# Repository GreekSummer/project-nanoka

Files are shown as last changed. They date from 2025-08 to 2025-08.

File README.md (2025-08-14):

# project-nanoka
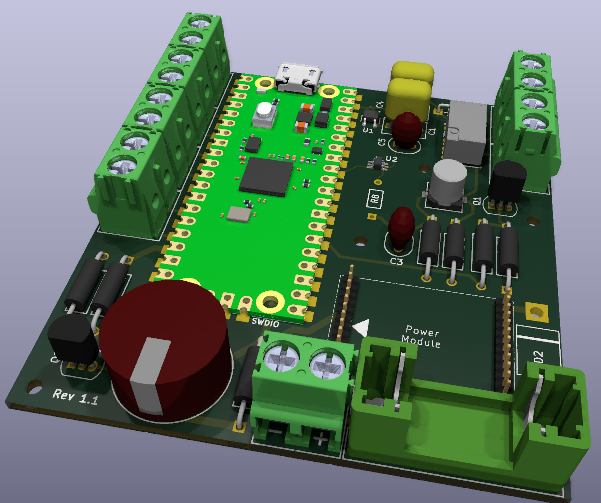
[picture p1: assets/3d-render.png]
KiCad 3D render


Project Nanoka is a Raspberry Pi Pico based audio output/input PCB. It exposes two audio terminals (input and output) as well as seven general-purposes input/output lines for external control. 

The PCB can be powered either through the Raspberry Pi's USB port, or through the power terminal. This requires a power module (also hosted on GitHub).

Right now, this is a prototype, and it's usefulness likely applies only to me. There are better solutions out there. I mainly created this to learn KiCad, and more broadly, PCB design which was always an interest of mine. This PCB should not be reproduced for your own personal use. If you do use it, **all responsibility is yours**. 

Known issues from previous version:
1. No audio output because the buffer chip is wired incorrectly (Input to A1, output to Y2)
2. Audio relay footprint is wrong
3. Audio relay footprint was accidentally flipped to the back of the board
4. C3 and C5 footprints are wrong
5. Audio input/output terminals are labelled in reverse
6. A potentiometer to adjust audio levels exists, but adjusting it below 220 ohms can cause damage to the Raspberry Pi

Fixed issues:
1. Audio is now properly routed from the buffer's A2 to Y2
2. Both relay issues have been fixed
3. Audio input/output terminals are labelled correctly and more clearly
4. C3 and C5 footprints fixed
5. Replaced potentiometer with a 220 ohm resistor

Improvements:
1. Replaced transistors with cheaper, more readily available ones
2. Tweaked transistor base resistor to draw less power from GPIO
4. Switched from a 4-layer setup to a 2-layer setup, making this cheaper to produce
5. Moved terminals closer to each other
6. General layout improvements
7. Symbols, footprints and 3D models are now packed in the repository

Ideas for the future:
1. Use a muxer IC to mix audio.
2. Switch from PWM audio to I2C audio for a cleaner signal.
3. Maybe re-design with SMD components to make this signafinantly smaller and elegant (but the THT components make it easier to assemble).

I have not yet re-produced this, so functionality and issues are unknown for this version.

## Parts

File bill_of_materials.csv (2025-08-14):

Country of Origin may be different at time of shipment.
The HTSUS and ECCN information shown is for informational purposes only and is not a representation or warranty as to the accuracy or reliability of these classifications. All information is provided "as is" and is subject to change without notice. Any use made of the information provided is without recourse to Digi-Key and at the user's risk.
Index | Manufacturer Part Number | Manufacturer Name | Description | Lead Time | Availability | Stock Status | Attrition % | Requested Quantity 1 | Pack Quantity 1 | Pack Type 1 | Digi-Key Part Number 1 | Unit Price 1 | Extended Price 1 | Minimum Order Quantity 1 | Customer Reference | Requested Part Number | Lead Weeks | Datasheet | Reference Designator | US Import Tariff | Note | Part Status | RoHS Status | Moisture Sensitivity Level (MSL) | ECCN | HTSUS | Country of Origin | Environmental Information | Original Part numbers | Image | Product Notes
1 | C330C105K5R5TA7301 | KEMET | CAP CER 1UF 50V X7R RADIAL | 2 past due; estimated in-stock on 01-Aug-2025 | 0 | Normally Stocking |  | 2 | 2 | Cut Tape (CT) | 399-9886-1-ND | 1.07000 | $2.14 | 1 | C1,C4 | 399-9886-1-ND | 12 | https://content.kemet.com/datasheets/KEM_C1050_GOLDMAX_X7R.pdf |  | - |  | Active | ROHS3 Compliant | Not Applicable | EAR99 | 8532.24.0060 | Mexico |  | 399-9886-1-ND | https://mm.digikey.com/Volume0/opasdata/d220001/medias/images/631/GoldenMax73-SERIES.jpg
2 | UUQ0J470MCL1GB | Nichicon | CAP ALUM 47UF 20% 6.3V SMD |  | 4,716 | In Stock |  | 1 | 1 | Cut Tape (CT) | 493-17489-1-ND | 0.53000 | $0.53 | 1 | C2 | 493-17489-1-ND | 25 | https://www.nichicon.co.jp/english/series_items/catalog_pdf/e-uuq.pdf |  | - |  | Active | ROHS3 Compliant | 1 (Unlimited) | EAR99 | 8532.22.0020 | Japan |  | 493-17489-1-ND | https://mm.digikey.com/Volume0/opasdata/d220001/medias/images/561/UUQ1E100MCL1GB.JPG
3 | 1N4148 | onsemi | DIODE STANDARD 100V 200MA DO35 |  | 179,368 | In Stock |  | 1 | 1 | Bulk | 1N4148FS-ND | 0.10000 | $0.10 | 1 | D1 | 1N4148FS-ND | 22 | https://www.onsemi.com/download/data-sheet/pdf/1n914-d.pdf |  | - |  | Active | ROHS3 Compliant | Not Applicable | EAR99 | 8541.10.0070 | China | https://www.onsemi.com/site/pdf/RoHS-statement.pdf|https://www.onsemi.com/PowerSolutions/MaterialComposition.do?export=pdf&opnId=1N4148 | 1N4148FS-ND | https://mm.digikey.com/Volume0/opasdata/d220001/medias/images/649/1N5229BFS.jpg
4 | 1N5408 | Diotec Semiconductor | DIODE STANDARD 1000V 3A DO201 |  | 12,757 | In Stock |  | 1 | 1 | Cut Tape (CT) | 4878-1N5408CT-ND | 0.33000 | $0.33 | 1 | D2 | 4878-1N5408CT-ND | 7 | https://diotec.com/request/datasheet/1n5400.pdf |  | - |  | Active | Not applicable | Not Applicable | EAR99 | 8541.10.0080 | China | https://diotec.com/request/imds/p3_e.pdf | 4878-1N5408CT-ND | https://mm.digikey.com/Volume0/opasdata/d220001/derivates/6/003/224/444/4878%7EDO201%7E%7E2_web%28640x640%29.jpg
5 | 696108003002 | Würth Elektronik | FUSEHOLDER BLOCKS - PCB - CLIP C | 1 past due; estimated in-stock on 04-Aug-2025 | 0 | Normally Stocking |  | 1 | 1 | Box | 732-11376-ND | 0.61000 | $0.61 | 1 | F1 | 732-11376-ND | 19 | https://www.we-online.com/katalog/datasheet/696108003002.pdf |  | - |  | Active | ROHS3 Compliant | Not Applicable | EAR99 | 8536.69.8000 | Romania | https://mm.digikey.com/Volume0/opasdata/d220001/medias/docus/744/Certificate_of_Compliance_ROHS.pdf | 732-11376-ND | https://mm.digikey.com/Volume0/opasdata/d220001/medias/images/2103/696108003002.JPG
6 | 696122003001 | Würth Elektronik | ACCESSORIES - PCB - CLIP COVER - |  | 16,278 | In Stock |  | 1 | 1 | Box | 732-11379-ND | 0.23000 | $0.23 | 1 | F1 | 732-11379-ND | 15 | https://www.we-online.com/katalog/datasheet/696122003001.pdf |  | - |  | Active | ROHS3 Compliant | Not Applicable | EAR99 | 8538.90.6000 | Romania | https://mm.digikey.com/Volume0/opasdata/d220001/medias/docus/744/Certificate_of_Compliance_ROHS.pdf | 732-11379-ND | https://mm.digikey.com/Volume0/opasdata/d220001/medias/images/2175/696122003001.JPG
7 | 1935161 | Phoenix Contact | TERM BLK 2POS SIDE ENTRY 5MM PCB |  | 83,502 | In Stock |  | 7 | 7 | Bulk | 277-1667-ND | 0.78000 | $5.46 | 1 | ST_20A | 277-1667-ND | 9 | https://mm.digikey.com/Volume0/opasdata/d220001/medias/docus/909/1935161.pdf |  | - |  | Active | ROHS3 Compliant | 1 (Unlimited) | EAR99 | 8536.90.4000 | China | https://www.phoenixcontact.com/en-us/products/product-compliance | 277-1667-ND | https://mm.digikey.com/Volume0/opasdata/d220001/medias/images/819/1935161.jpg
8 | IM03TS | TE Connectivity Potter & Brumfield Relays | RELAY TELECOM DPDT 2A 5V |  | 11,388 | In Stock |  | 1 | 1 | Tube | PB1094-ND | 4.55000 | $4.55 | 1 | K1 | PB1094-ND | 27 | https://www.te.com/commerce/DocumentDelivery/DDEController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 |  | - |  | Active | ROHS3 Compliant | 1 (Unlimited) | EAR99 | 8536.41.0020 | Portugal |  | PB1094-ND | https://mm.digikey.com/Volume0/opasdata/d220001/medias/images/666/IM-PC-SERIES.jpg
9 | CF14JT100R | Stackpole Electronics Inc | RES 100 OHM 5% 1/4W AXIAL |  | 197,065 | In Stock |  | 1 | 1 | Cut Tape (CT) | CF14JT100RCT-ND | 0.10000 | $0.10 | 1 | R2 | CF14JT100RCT-ND | 22 | https://www.seielect.com/catalog/sei-cf_cfm.pdf |  | - |  | Active | ROHS3 Compliant | Not Applicable | EAR99 | 8533.10.0065 | China | https://www.seielect.com/catalog/SEI-RoHS_Compliance_Status.pdf|https://www.seielect.com/catalog/reach.pdf|https://www.seielect.com/catalog/sei-coc%20prop%2065.pdf | CF14JT100RCT-ND | https://mm.digikey.com/Volume0/opasdata/d220001/medias/images/2367/CF%20100.jpg
10 | MFR-25FRF52-10K | YAGEO | RES 10K OHM 1% 1/4W AXIAL |  | 22,514 | In Stock |  | 2 | 2 | Cut Tape (CT) | 13-MFR-25FRF52-10KCT-ND | 0.10000 | $0.20 | 1 | R3,R6 | 13-MFR-25FRF52-10KCT-ND | 16 | https://www.yageo.com/upload/media/product/app/datasheet/lr/yageo-mfr_datasheet.pdf |  | - |  | Active | ROHS3 Compliant | Not Applicable | EAR99 | 8533.21.0090 | China |  | 13-MFR-25FRF52-10KCT-ND | https://mm.digikey.com/Volume0/opasdata/d220001/medias/images/1206/MFR-25FRF52-10K.jpg
11 | CF14JT1K80 | Stackpole Electronics Inc | RES 1.8K OHM 5% 1/4W AXIAL |  | 39,281 | In Stock |  | 1 | 1 | Cut Tape (CT) | CF14JT1K80CT-ND | 0.10000 | $0.10 | 1 | R1 | CF14JT1K80CT-ND | 22 | https://www.seielect.com/catalog/sei-cf_cfm.pdf |  | - |  | Active | ROHS3 Compliant | Not Applicable | EAR99 | 8533.10.0065 | China | https://www.seielect.com/catalog/SEI-RoHS_Compliance_Status.pdf|https://www.seielect.com/catalog/reach.pdf|https://www.seielect.com/catalog/sei-coc%20prop%2065.pdf | CF14JT1K80CT-ND | https://mm.digikey.com/Volume0/opasdata/d220001/medias/images/2497/CF%201-8k.jpg
12 | CF14JT1K20 | Stackpole Electronics Inc | RES 1.2K OHM 5% 1/4W AXIAL |  | 32,620 | In Stock |  | 1 | 1 | Cut Tape (CT) | CF14JT1K20CT-ND | 0.10000 | $0.10 | 1 | ??? | CF14JT1K20CT-ND | 22 | https://www.seielect.com/catalog/sei-cf_cfm.pdf |  | - |  | Active | ROHS3 Compliant | Not Applicable | EAR99 | 8533.10.0065 | China | https://www.seielect.com/catalog/SEI-RoHS_Compliance_Status.pdf|https://www.seielect.com/catalog/reach.pdf|https://www.seielect.com/catalog/sei-coc%20prop%2065.pdf | CF14JT1K20CT-ND | https://mm.digikey.com/Volume0/opasdata/d220001/medias/images/2515/CF%201-2k.jpg
13 | NC7WZ16P6X | onsemi | IC BUFFER NON-INVERT 5.5V SC-88 | 1 expected in stock on 25-Aug-2025 | 0 | Normally Stocking |  | 1 | 1 | Cut Tape (CT) | NC7WZ16P6XCT-ND | 0.10000 | $0.10 | 1 | U2 | NC7WZ16P6XCT-ND | 6 | https://www.onsemi.com/pub/Collateral/NC7WZ16-D.PDF |  | - |  | Active | ROHS3 Compliant | 1 (Unlimited) | EAR99 | 8542.39.0070 | Taiwan | https://www.onsemi.com/site/pdf/RoHS-statement.pdf|https://www.onsemi.com/site/pdf/REACH-compliance-statement.pdf | NC7WZ16P6XCT-ND | https://mm.digikey.com/Volume0/opasdata/d220001/medias/images/6164/488%7EMKT-MAA06A%7E%7E6.jpg
14 | PS1440P02BT | TDK Corporation | BUZZER PIEZO 3V 14MM TH |  | 220 | In Stock |  | 1 | 1 | Cut Tape (CT) | 445-5242-1-ND | 0.69000 | $0.69 | 1 | U3 | 445-5242-1-ND | 8 | https://product.tdk.com/en/system/files |  | - |  | Active | ROHS3 Compliant | 1 (Unlimited) | EAR99 | 8531.80.9041 | China | https://product.tdk.com/en/environment/index.html | 445-5242-1-ND | https://mm.digikey.com/Volume0/opasdata/d220001/medias/images/2905/PS-PC%20SERIES.JPG
15 | TLV70033DDCR | Texas Instruments | IC REG LINEAR 3.3V 200MA SOT23 |  | 3,075 | In Stock |  | 1 | 1 | Cut Tape (CT) | 296-27937-1-ND | 0.23000 | $0.23 | 1 | U1 | 296-27937-1-ND | 12 | https://www.ti.com/general/docs/suppproductinfo.tsp?distId=10 |  | - |  | Active | ROHS3 Compliant | 2 (1 Year) | EAR99 | 8542.39.0090 | China |  | 296-27937-1-ND | https://mm.digikey.com/Volume0/opasdata/d220001/medias/images/6286/296%7E4204403-2%7EDDC%7E5.jpg
16 | 0ADKC0500-BE | Bel Fuse Inc. | FUSE CERM 500MA 600VAC 500VDC |  | 1,962 | In Stock |  | 1 | 1 | Bulk | 5923-0ADKC0500-BE-ND | 2.18000 | $2.18 | 1 | F1 | 5923-0ADKC0500-BE-ND | 11 | https://belfuse.com/media/datasheets/products/circuit-protection/ds-cp-0adkx-series.pdf |  | - |  | Active | ROHS3 Compliant | 1 (Unlimited) | EAR99 | 8536.10.0040 | China | https://www.belfuse.com/resource-center/quality-environmental/documents/bel%20fuse/environmental/Declaration%20of%20EU%20RoHS%20Compliance.pdf|https://www.belfuse.com:443/resource-center/quality-environmental/documents/bel%20fuse/environmental/REACH%20SVHC%20201%20Declaration.pdf | 5923-0ADKC0500-BE-ND | https://mm.digikey.com/Volume0/opasdata/d220001/medias/images/2444/5HT%2C5HF%20SERIES.jpg
17 | C320C104K5R5TA7305 | KEMET | CAP CER 0.1UF 50V X7R RADIAL |  | 23,338 | In Stock |  | 2 | 2 | Cut Tape (CT) | 399-C320C104K5R5TA7305CT-ND | 0.30000 | $0.60 | 1 | C3,C5 | 399-C320C104K5R5TA7305CT-ND | 16 | https://content.kemet.com/datasheets/KEM_C1050_GOLDMAX_X7R.pdf |  | - |  | Active | ROHS3 Compliant | Not Applicable | EAR99 | 8532.24.0060 | Mexico |  | 399-C320C104K5R5TA7305CT-ND | https://mm.digikey.com/Volume0/opasdata/d220001/medias/images/2079/Goldmax%2C-300.jpg
18 | 2N3904BU | onsemi | TRANS NPN 40V 0.2A TO-92-3 |  | 44,993 | In Stock |  | 2 | 2 | Bulk | 2N3904FS-ND | 0.28000 | $0.56 | 1 | Q1,Q2 | 2N3904FS-ND | 10 | https://www.onsemi.com/pdf/datasheet/pzt3904-d.pdf |  | - |  | Active | ROHS3 Compliant | Not Applicable | EAR99 | 8541.21.0075 | China | https://www.onsemi.com/site/pdf/RoHS-statement.pdf|https://www.onsemi.com/site/pdf/REACH-compliance-statement.pdf|https://www.onsemi.com/PowerSolutions/MaterialComposition.do?export=pdf&opnId=2N3904BU | 2N3904FS-ND | https://mm.digikey.com/Volume0/opasdata/d220001/medias/images/6157/488%7EMKT-ZA03D%7E%7E3.jpg
19 | RNF14FTD1K00 | Stackpole Electronics Inc | RES 1K OHM 1% 1/4W AXIAL |  | 131,863 | In Stock |  | 2 | 2 | Cut Tape (CT) | RNF14FTD1K00CT-ND | 0.10000 | $0.20 | 1 | R4,R5 | RNF14FTD1K00CT-ND | 22 | https://www.seielect.com/catalog/sei-rnf_rnmf.pdf |  | - |  | Active | ROHS3 Compliant | Not Applicable | EAR99 | 8533.21.0090 | China | https://www.seielect.com/catalog/SEI-RoHS_Compliance_Status.pdf|https://www.seielect.com/catalog/reach.pdf|https://www.seielect.com/catalog/sei-coc%20prop%2065.pdf | RNF14FTD1K00CT-ND | https://mm.digikey.com/Volume0/opasdata/d220001/medias/images/2603/RNF-1KOhm1%25.jpg
20 | RNMF14FTC220R | Stackpole Electronics Inc | RES 220 OHM 1% 1/4W AXIAL |  | 18,001 | In Stock |  | 1 | 1 | Cut Tape (CT) | S220CACT-ND | 0.10000 | $0.10 | 1 | R8 | S220CACT-ND | 22 | https://www.seielect.com/catalog/sei-rnf_rnmf.pdf |  | - |  | Active | ROHS3 Compliant | Not Applicable | EAR99 | 8533.21.0090 | China | https://www.seielect.com/catalog/SEI-RoHS_Compliance_Status.pdf|https://www.seielect.com/catalog/reach.pdf|https://www.seielect.com/catalog/sei-coc%20prop%2065.pdf | S220CACT-ND | https://mm.digikey.com/Volume0/opasdata/d220001/medias/images/2609/RNMF14%20220.jpg

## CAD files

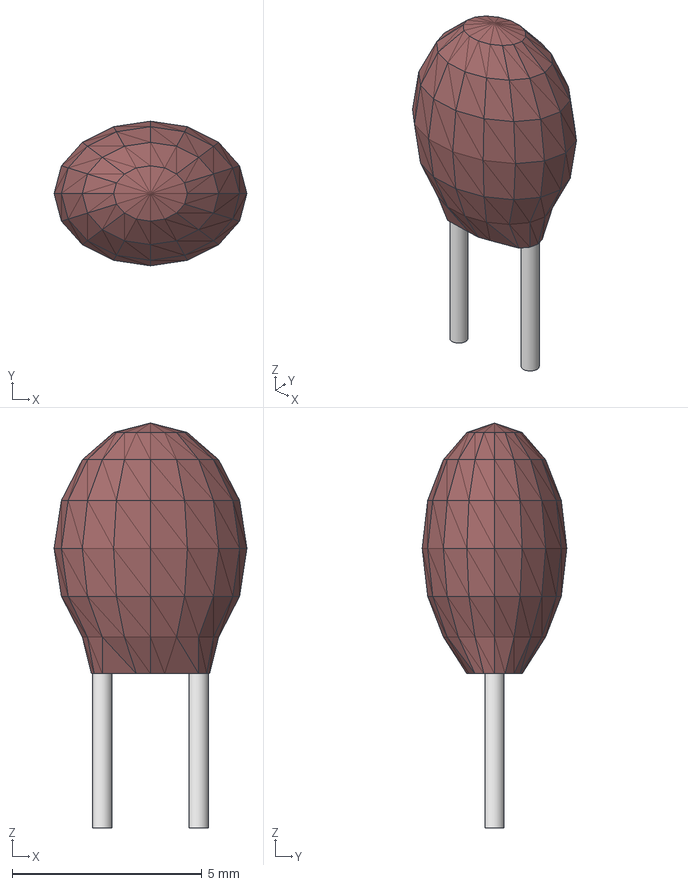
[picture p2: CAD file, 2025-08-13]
assets/3d_models/CAP_C320_KEM.step
5.08 x 3.81 x 10.7 mm

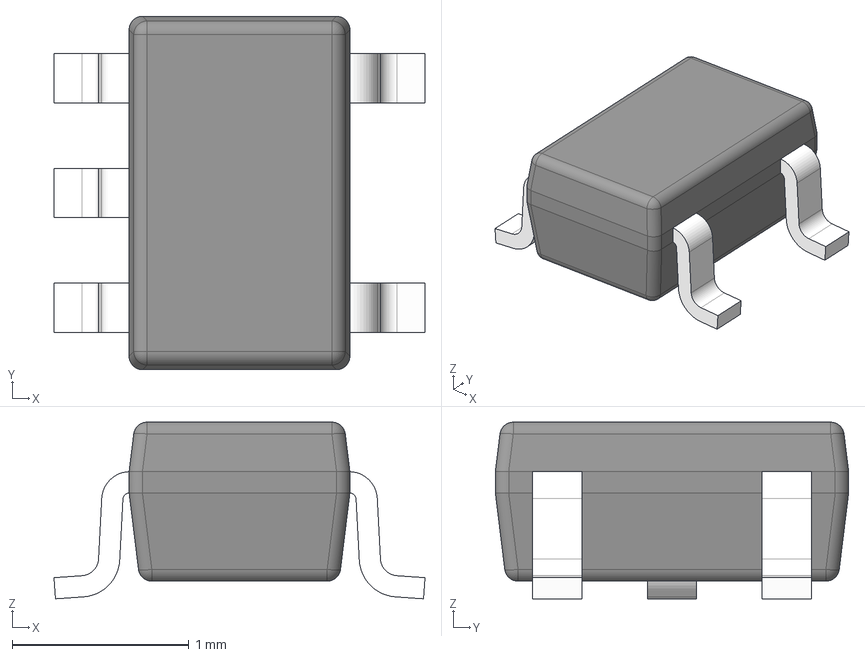
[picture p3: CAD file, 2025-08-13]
assets/3d_models/DCK0005A.stp
2.10 x 2.00 x 1.00 mm
BODY-SOT
LEAD-SOT x 5
PIN1-ID

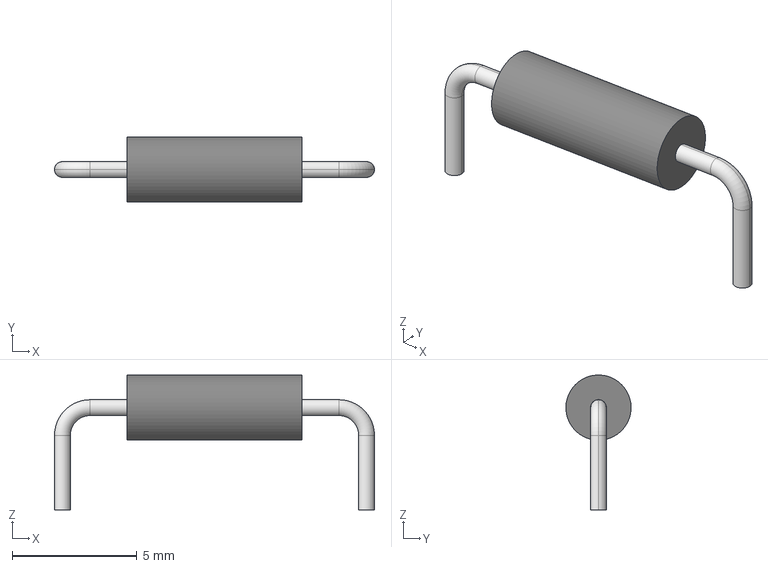
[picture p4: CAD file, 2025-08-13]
assets/3d_models/STA_RNF14_STP.step
12.8 x 2.61 x 5.41 mm

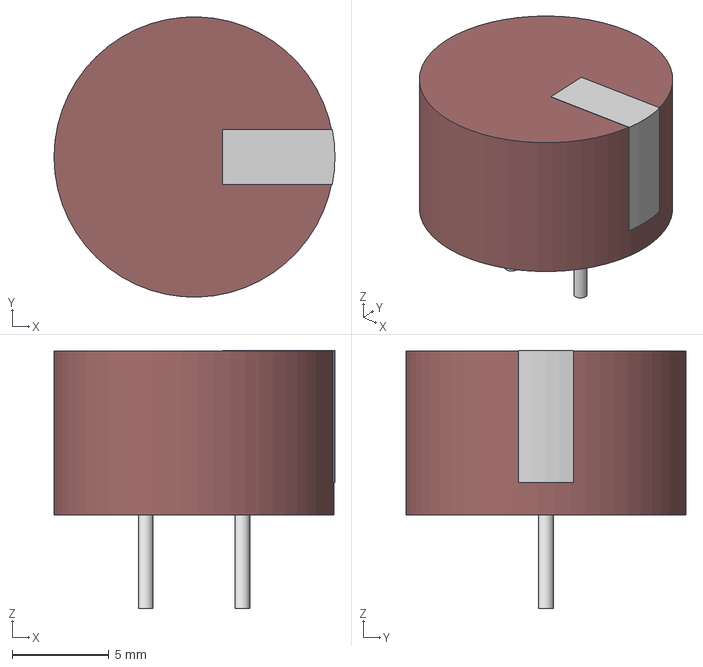
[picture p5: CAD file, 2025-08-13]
assets/3d_models/PS1440P02BT_TDK.step
14.5 x 14.5 x 13.4 mm

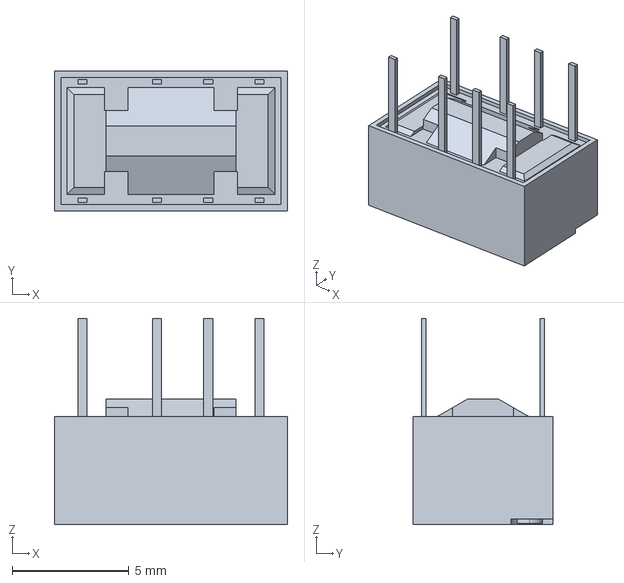
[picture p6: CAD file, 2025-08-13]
assets/3d_models/c-1462037-4-a7-3d.stp
10.0 x 6.00 x 8.85 mm

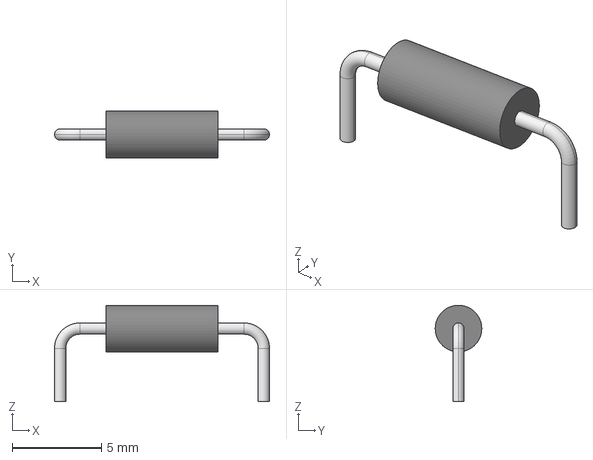
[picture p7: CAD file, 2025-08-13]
assets/3d_models/STA_CF14_STP.step
12.1 x 2.61 x 5.41 mm

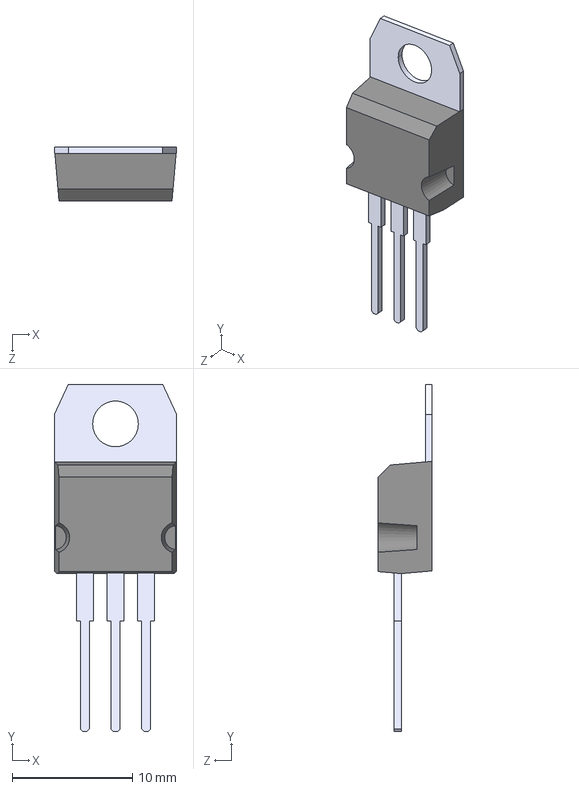
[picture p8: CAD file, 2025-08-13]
assets/3d_models/L7805CV.step
10.2 x 28.9 x 4.50 mm

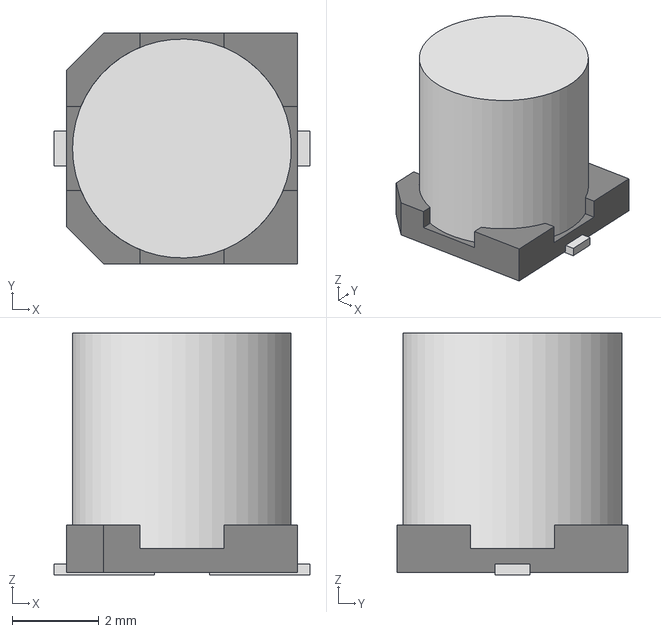
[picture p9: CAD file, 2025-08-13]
assets/3d_models/CAP_UUQ_5X5P4_NCH.step
5.89 x 5.31 x 5.57 mm

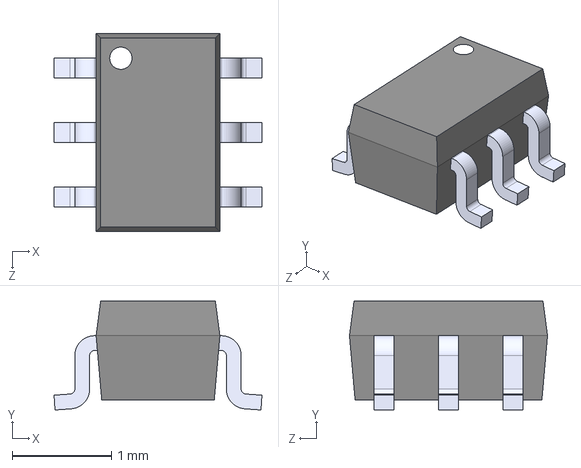
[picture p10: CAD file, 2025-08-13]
assets/3d_models/NC7WZ16P6X.step
2.10 x 1.10 x 2.00 mm

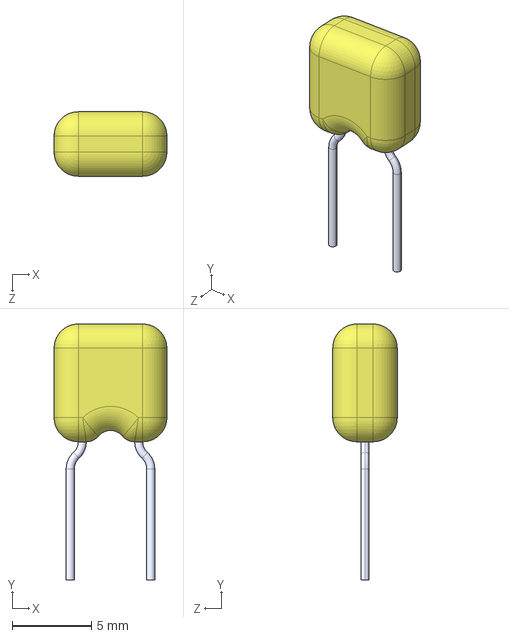
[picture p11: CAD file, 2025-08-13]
assets/3d_models/C330C105K5R5TA7301.STEP
7.11 x 16.1 x 4.07 mm

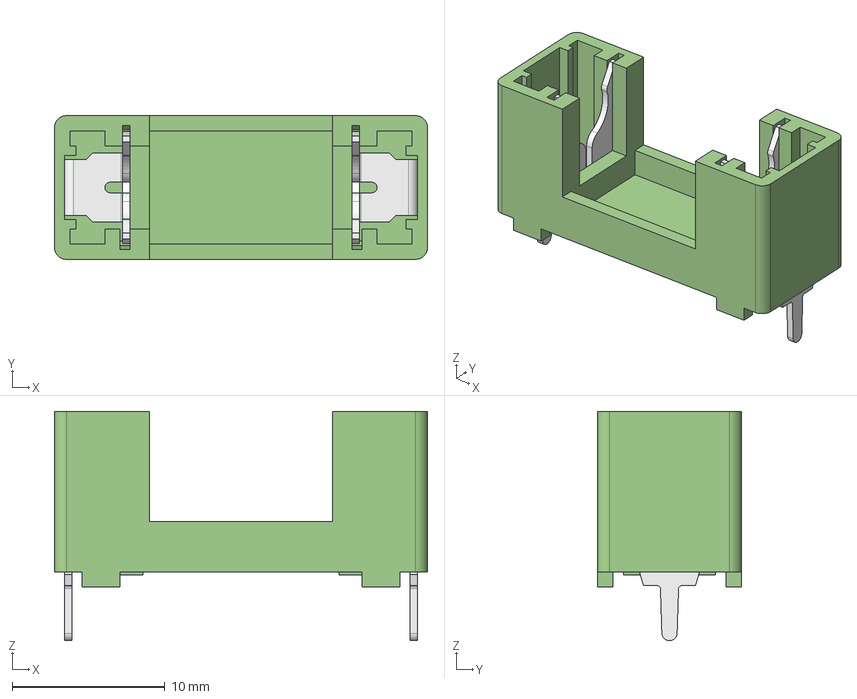
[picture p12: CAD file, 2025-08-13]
assets/3d_models/696108003002.stp
24.4 x 9.40 x 15.0 mm

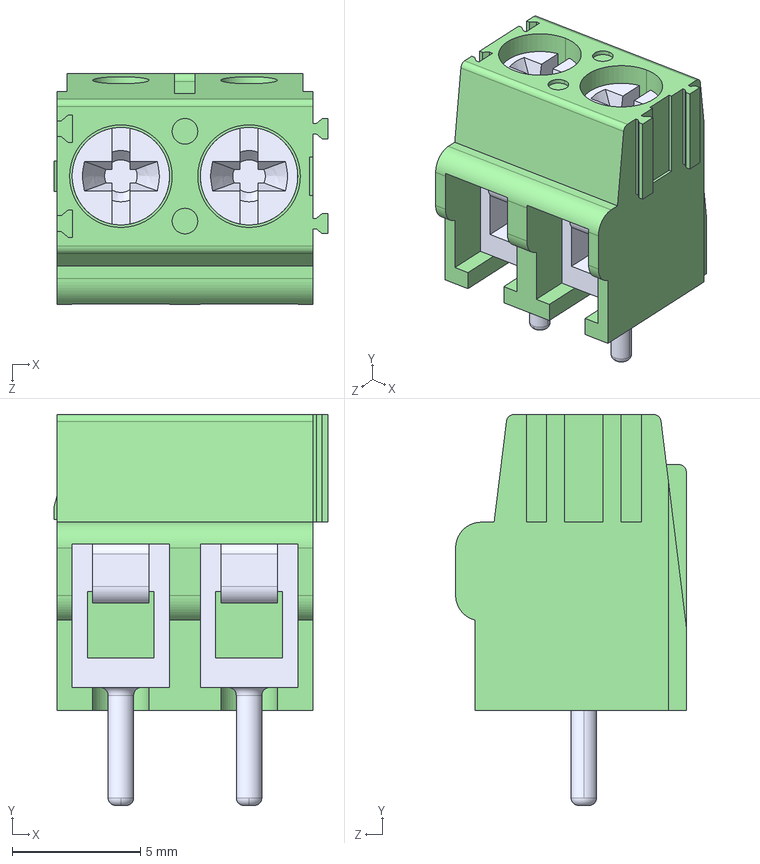
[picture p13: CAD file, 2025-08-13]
assets/3d_models/1935161.STEP
10.7 x 15.2 x 9.00 mm

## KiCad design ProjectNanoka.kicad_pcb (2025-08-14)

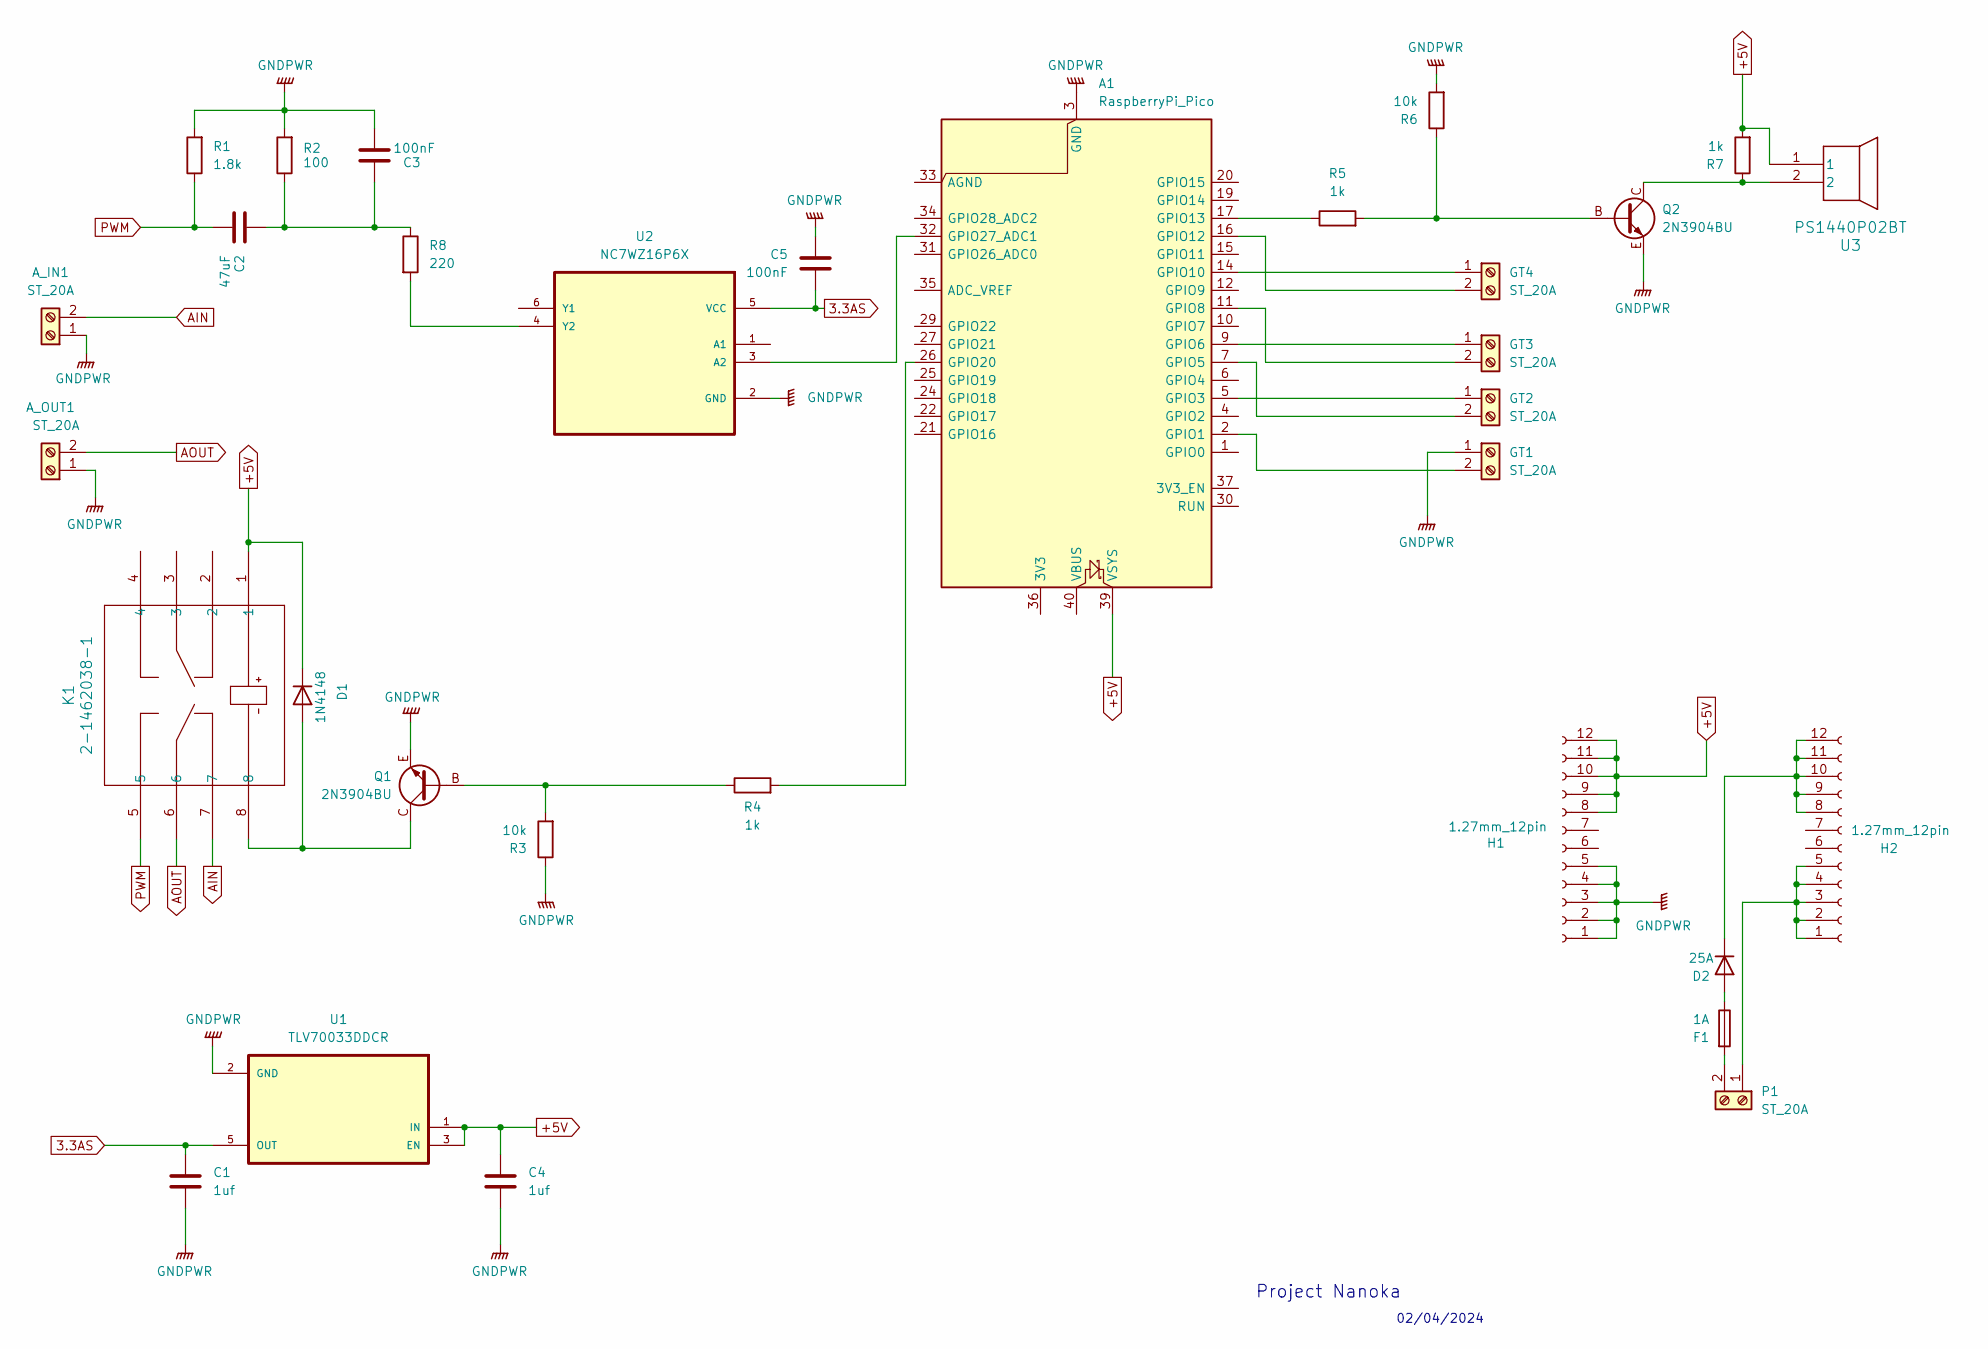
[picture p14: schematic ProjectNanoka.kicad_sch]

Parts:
A1: RaspberryPi_Pico; RPi_Pico_SMD_TH
A_IN1: ST_20A; CONN_1935161_PXC
A_OUT1: ST_20A; CONN_1935161_PXC
C1, C4: 1uf; CAP_C330C_MR_X7R_KEM
C2: 47uF; CAP_UUQ_5X5P4_NCH
C3, C5: 100nF; CAP_C320_KEM
D1: 1N4148; D_DO-35_SOD27_P7.62mm_Horizontal
D2: 25A; P33_D5.4x7.5
F1: 1A; 20x300_FUSE_HOLDER_0PTF0078P_LTF
GT1, GT2, GT3, GT4: ST_20A; CONN_1935161_PXC
H1, H2: 1.27mm_12pin; PinHeader_1x12_P1.27mm_Vertical_Modded
K1: 2-1462038-1; RELAY8-TH_NON-LATCH_1-COIL
P1: ST_20A; CONN_1935161_PXC
Q1, Q2: 2N3904BU
R1: 1.8k; STA_CF14_STP
R2: 100; STA_CF14_STP
R3, R6: 10k; STA_RNF14_STP
R4, R5, R7: 1k; STA_RNF14_STP
R8: 220; STA_RNMF14_STP
U1: TLV70033DDCR; SOT95P280X110-5N
U2: NC7WZ16P6X; SOT65P210X110-6N; MPN NC7WZ16P6X
U3: PS1440P02BT; PS1440P02BT_TDK

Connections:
3.3AS: C1.1, C5.1, U1.5 (OUT), U2.5 (VCC)
+5V: A1.39 (VSYS), C4.1, D1.1 (K), H1.8, H1.9, H1.10, H1.11, H1.12, K1.1, R7.2, U1.1 (IN), U1.3 (EN), U3.1
AIN: A_IN1.2, K1.7
AOUT: A_OUT1.2, K1.6
GNDPWR: A1.3 (GND), A1.8 (GND), A1.13 (GND), A1.18 (GND), A1.23 (GND), A1.28 (GND), A1.38 (GND), A_IN1.1, A_OUT1.1, C1.2, C3.2, C4.2, C5.2, GT1.1, H1.1, H1.2, H1.3, H1.4, H1.5, Q1.E, Q2.E, R1.2, R2.2, R3.1, R6.2, U1.2 (GND), U2.2 (GND)
unnamed: A1.2 (GPIO1), GT1.2
unnamed: A1.5 (GPIO3), GT2.1
unnamed: A1.7 (GPIO5), GT2.2
unnamed: A1.9 (GPIO6), GT3.1
unnamed: A1.11 (GPIO8), GT3.2
unnamed: A1.14 (GPIO10), GT4.1
unnamed: A1.16 (GPIO12), GT4.2
unnamed: A1.17 (GPIO13), R5.1
unnamed: A1.26 (GPIO20), R4.2
unnamed: A1.32 (GPIO27_ADC1), U2.3 (A2)
unnamed: C2.1, C3.1, R2.1, R8.1
unnamed: D1.2 (A), K1.8, Q1.C
unnamed: D2.2 (A), F1.1
unnamed: D2.1 (K), H2.8, H2.9, H2.10, H2.11, H2.12
unnamed: H2.1, H2.2, H2.3, H2.4, H2.5, P1.1
unnamed: F1.2, P1.2
unnamed: Q1.B, R3.2, R4.1
unnamed: Q2.B, R5.2, R6.1
unnamed: Q2.C, R7.1, U3.2
unnamed: R8.2, U2.4 (Y2)
PWM: C2.2, K1.5, R1.1

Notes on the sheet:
Project Nanoka
02/04/2024

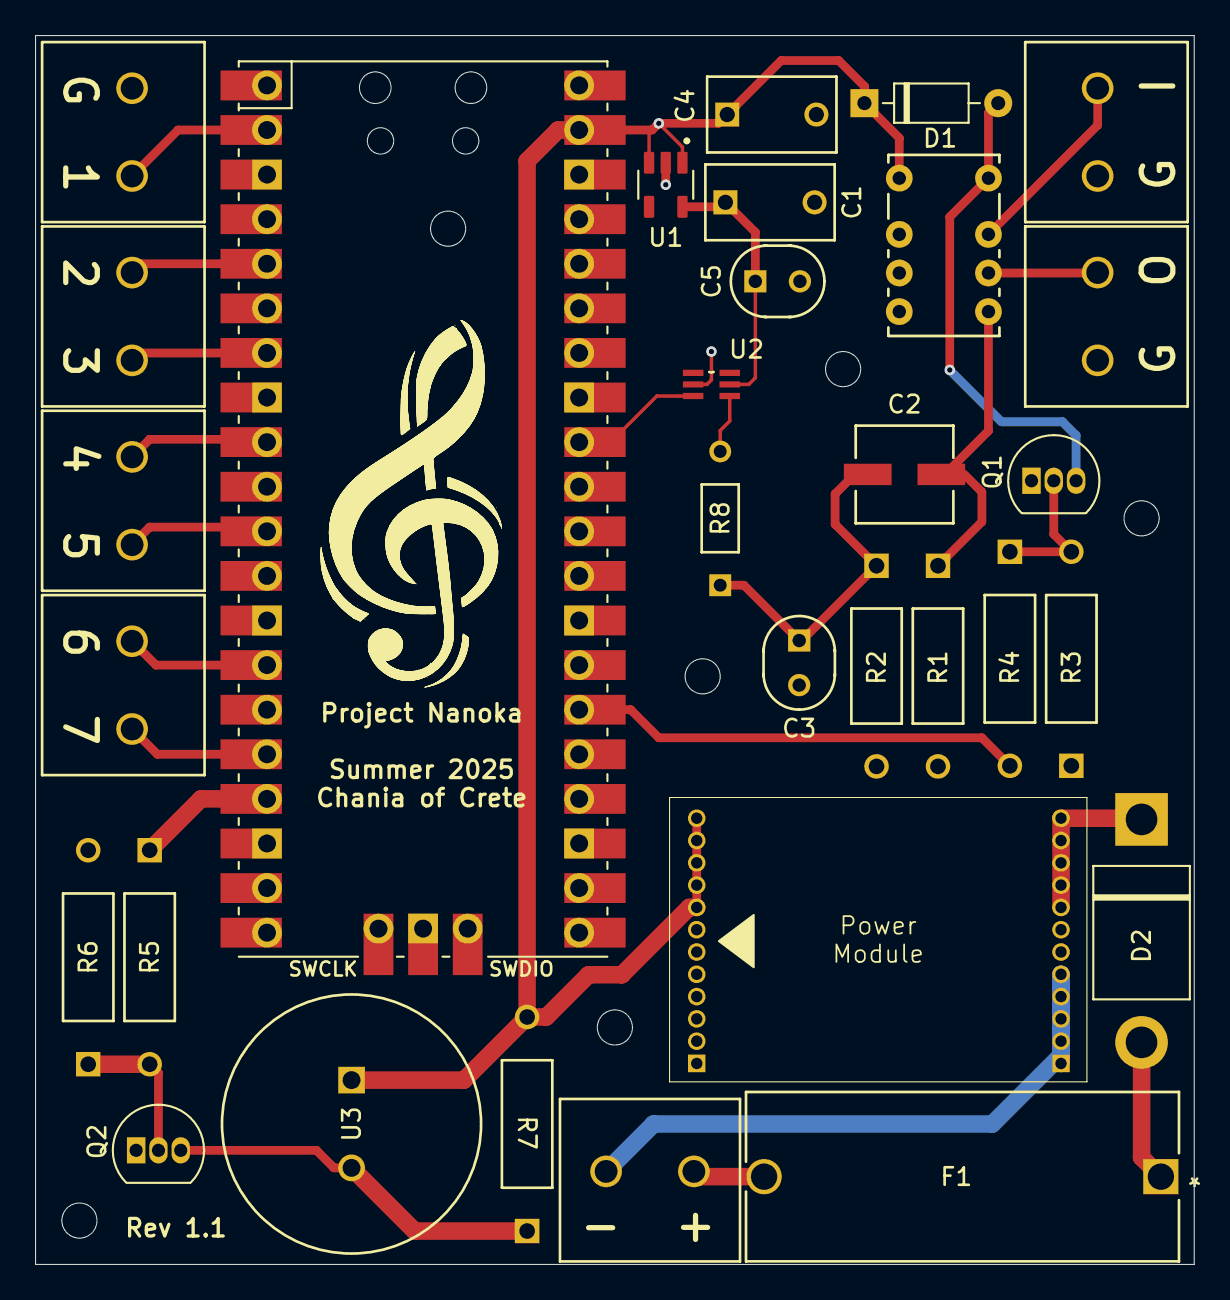
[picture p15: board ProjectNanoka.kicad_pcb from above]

Board: 2 copper layers, 66.0 x 70.0 mm, 32 parts (0 on the bottom side), 26 nets.

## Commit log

2025-08-13 Fix issues found in v1
    [ProjectNanoka.kicad_pcb, ProjectNanoka.kicad_sch]
2025-08-13 Make improvements to board
    [ProjectNanoka.kicad_pcb, ProjectNanoka.kicad_sch]
2025-08-13 Embed libraries and 3d models
    [1935161.STEP, 696108003002.stp, C330C105K5R5TA7301.STEP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]
2025-08-14 Replaced 2SC1815 with 2N3904BU
    [ProjectNanoka.kicad_pcb, ProjectNanoka.kicad_sch]
2025-08-14 Replaced RV1 with a 220ohm resistor
    [ProjectNanoka.kicad_pcb, ProjectNanoka.kicad_sch]
2025-08-14 Add DigiKey BOM
    [bill_of_materials.csv]
